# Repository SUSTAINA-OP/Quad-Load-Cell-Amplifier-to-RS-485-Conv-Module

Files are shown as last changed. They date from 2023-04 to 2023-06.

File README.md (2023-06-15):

<html lang="en">

<head>
	<meta charset="uft-8">
	<meta name="author" content="Masato Kubotera">
    <meta name="description" content="">
</head>

<body>
    <p><strong>This product is currently under development!</strong></p>
	<h1>Quad Load Cell Amplifier to RS-485 Conv. Module</h1>
        <p>
            This product can connect up to four load cells, and the change in resistance of the load cells can be amplified by an amplifier to 24 bit and sensed by a microcontroller at 80 Hz. This product uses a ready-made microcontroller board, simplifying PCB design and assembly of electronic components. For communication with the microcontroller, in addition to the USB connector on the microcontroller, RS-485 converted from UART  is available.<br>
            The RS-485 I/F connector has power input of up to 15 V. This allows servo motors with RS-485 I/F to be connected to the same bus as servo motors, etc.<br>
            The microcontroller that can be attached to this product is the <a href="https://www.seeedstudio.com/XIAO-c-1964.html?">XIAO series</a> manufactured by Seeed Studio. Select a microcontroller from the lineup according to the required performance.
            <br>
            <br>
            This product is developed as a foot load measurement module for SUSTAINA-OP<sup>TM</sup> and is used, for example, to estimate the position of the robot's center of mass.<br>
            In SUSTAINA-OP<sup>TM</sup>, four of the following load cells are connected to this module.
            <ul>
                <li><a href="https://www.alibaba.com/product-detail/SC700-Fishing-Scales-Small-Size-thin_60710601230.html">SC700-40kg (Sensor and Control Co., Ltd.)</a></li>
            </ul>
            The following microcontrollers are attached to this module.
            <ul>
                <li><a href="https://www.seeedstudio.com/Seeeduino-XIAO-Arduino-Microcontroller-SAMD21-Cortex-M0+-p-4426.html?">XIAO SAMD21 (Seeed Studio)</a></li>
            </ul>     
        </p>
	<h2>Features Rev. 1</h2>
        <p>
            <table>
                <tr>
                    <th>Top Surface of PCB</th>
                    <th>Bottom Surface of PCB</th>
                    <th>Assembled Electronic Components</th>
                </tr>
                <tr>
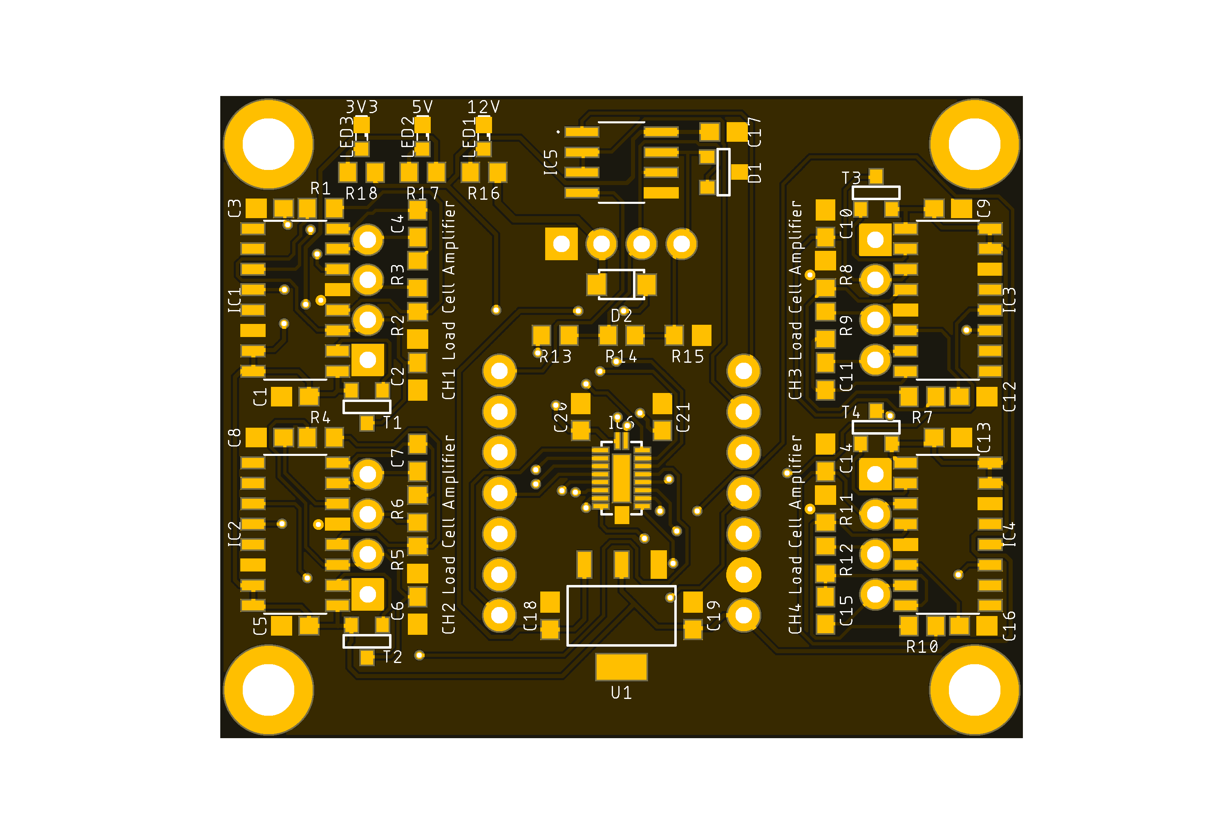
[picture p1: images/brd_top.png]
                    <td></td>
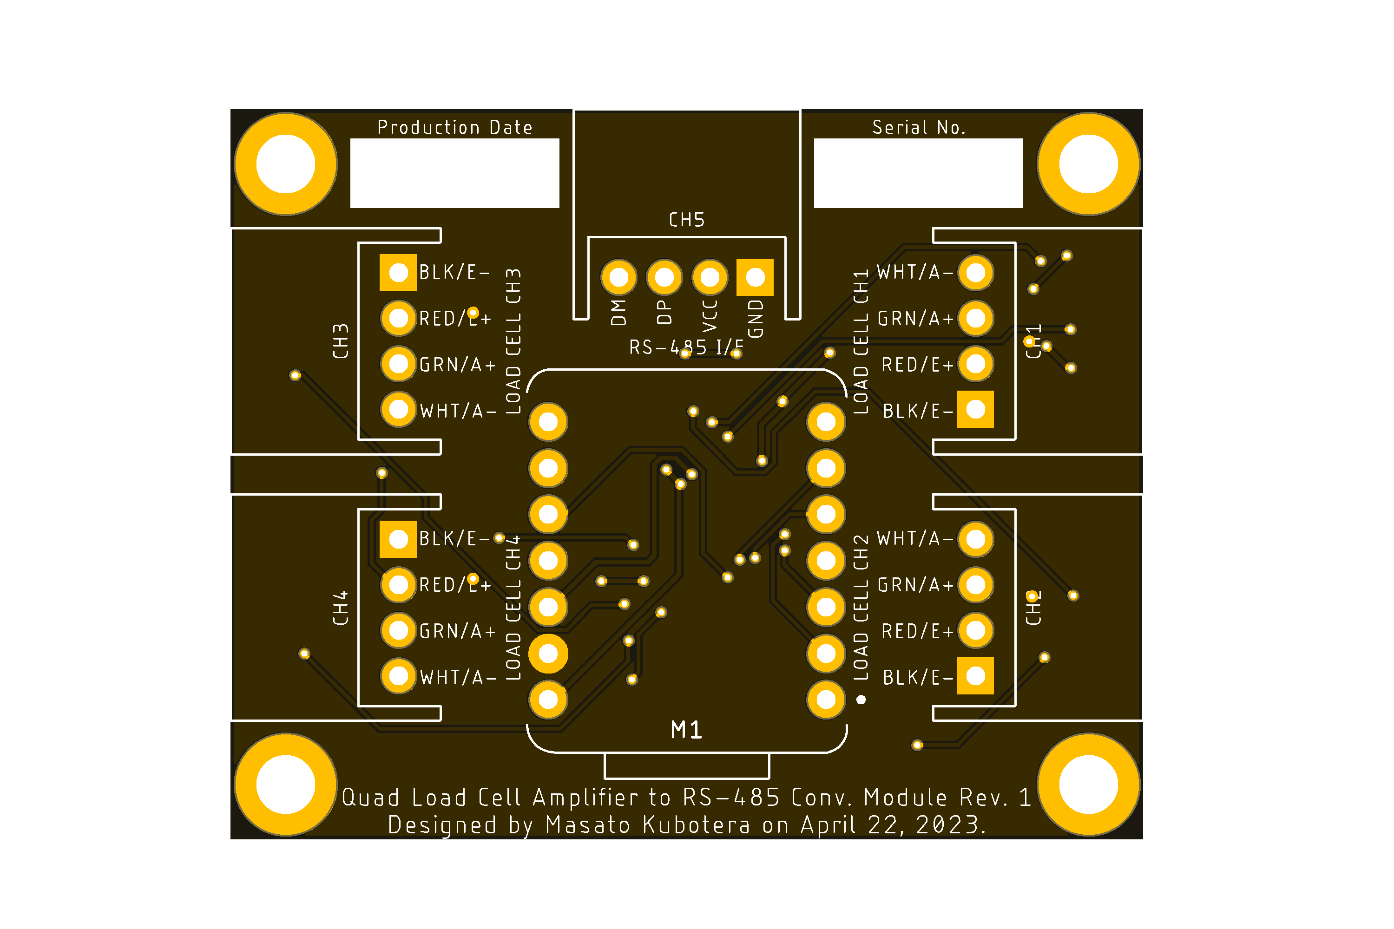
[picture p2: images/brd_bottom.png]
                    <td></td>
                    <td></td>
                </tr>
            </table>
        </p>
    <h3>PCB</h3>
        <p>
            <ul>
                <li>50 mm x 40 mm PCB layout</li>
                <li>4 x ø3.2 Mounting Holes</li>
                <li>
                    4 x Load Cell Ports
                    <ul>
                        <li>1" (2.54mm) pitch through-holes for XH connecter(JST)
                            <ul>
                                <li>BLK/E-: Excitation- (E-) or GND</li>
                                <li>RED/E+: Excitation+ (E+) or VCC</li>
                                <li>GRN/A+: Output+, Signal+, or Amplifier+</li>
                                <li>WHT/A-: Output-, Signal-, or Amplifier-</li>
                            </ul>
                        </li>
                    </ul>
                </li>
                <li>
                    1 x RS-485 I/F Port
                    <ul>
                        <li>1" (2.54mm) pitch through-holes for XH connecter(JST)
                            <ul>
                                <li>DM: RS-485 Data Signal Minus</li>
                                <li>DP: RS-485 Data Signal Plus</li>
                                <li>VCC: Power Input (Input voltage: 6.2~15V)</li>
                                <li>GND: Common Ground</li>
                            </ul>
                        </li>
                    </ul>
                </li>
            </ul>
        </p>
    <h3><a href="http://en.aviaic.com/detail/730856.html">AVIA HX711</a></h3>
        <p>
            <ul>
                <li>Two selectable differential input channels</li>
                <li>On-chip active low noise PGA with selectable gain of 32, 64 and 128</li>
                <li>On-chip power supply regulator for load-cell and ADC analog power supply</li>
                <li>On-chip oscillator requiring no external component with optional external crystal</li>
                <li>On-chip power-on-reset</li>
                <li>Simple digital control and serial interface: pin-driven controls, no programming needed</li>
                <li>Selectable 10SPS or 80SPS output data rate</li>
                <li>Simultaneous 50 and 60Hz supply rejection</li>
                <li>Current consumption including on-chip analog power supply regulator: normal operation < 1.5mA, power down < 1uA</li>
                <li>Operation supply voltage range: 2.6 ~ 5.5V</li>
                <li>Operation temperature range: -40 ~ +85C</li>
                <li>16 pin SOP-16 package</li>
            </ul>
        <p>
	<h2>Development Environments</h2>
    <p>
        This product is designed with the following software.
            <ul>
                <li><a href="https://www.autodesk.com/products/eagle/overview">Autodesk Eagle 9.6.2</a></li>
            </ul>
    </p>
    <h2>Repository Contents</h2>
        <p>
            <dl>
                <dt><a href="/images">\images</a></dt>
                <dd>PCB preview images and capture of design screen</dd>
                <dt><a href="/libraries">\libraries</a></dt>
                <dd>Libraries used in Autodesk Eagle design</dd>
                <dt><a href="/documents">\documents</a> </dt>
                <dd>Documentation for making and using this product</dd>
                <dt><a href="/pcb_order">\pcb_order</a> </dt>
                <dd>Gerber data and documentation for ordering PCB</dd>
                <dt><a href="/schematic.pdf">schematic.pdf</a></dt>
                <dd>Circuit diagram of this product</dd>
                <dt>*.brd</dt>
                <dd>Board wiring design file by Autodesk Eagle</dd>
                <dt>*.sch</dt>
                <dd>Circuit diagram design file by Autodesk Eagle</dd>
                <dt><a href="/.gitignore">.gitignore</a></dt>
                <dd>A file that tells Git not to track a particular file</dd>            <dt><a href="/LICENSE">LICENSE</a></dt>
                <dd>License to use this product</dd>
            </dl>
        </p>
    <h2>Documentation</h2>
        <p>
            The following documents are available for this product.
            <ul>
                <li><a href="/pcb_order/README.md">\pcb_order\README.md</a>: Information for ordering the PCB</li>
                <li><a href="/documents/BOM.md">\document\BOM.md</a>: List of electronic components assembled on the PCB</li>
            </ul>
        </p>
    <h2>References</h2>
        <p>
            This product was designed with reference to the following products.
            <ul>
                <li><a href="https://www.sparkfun.com/products/13879">SparkFun Load Cell Amplifier - HX711</a></li>
            </ul>
        </p>
    <h3>Acknowledgements</h3>
        <p>
            The development of this module is based on the following foot load measurement modules in the RoboCup Humanoid League.
            <ul>
                <li><a href="https://github.com/Rhoban/ForceFoot">Rhoban/ForceFoot</a>: Robotic foot design involving force sensors</li>
                <li><a href="https://github.com/bit-bots/bit_foot">bit-bots/bit_foot</a>: Foot pressure sensor for a humanoid robot</li>
            </ul>
            I would like to take this opportunity to thank you.
        </p>
    <h2>Contact</h2>
        <p>
            If you have any questions, please contact the designer of this product, Masato Kubodera, by <a href="mailto:masato.kubotera@sustaina-op.com">e-mail</a>.<br>
            E-mail: <a href="mailto:masato.kubotera@sustaina-op.com">masato.kubotera@sustaina-op.com</a>
        </p>
    <h2>License Information</h2>
        <p>
            This product is open source. Please review the <a href="/LICENSE">LICENSE</a> for license information.<br>
            <br>
            This product by Masato Kubotera is licensed under a <a href="http://creativecommons.org/licenses/by-nc-sa/4.0/">Creative Commons Attribution-NonCommercial-ShareAlike 4.0 International License</a>.
        </p>    
</body>
</html>

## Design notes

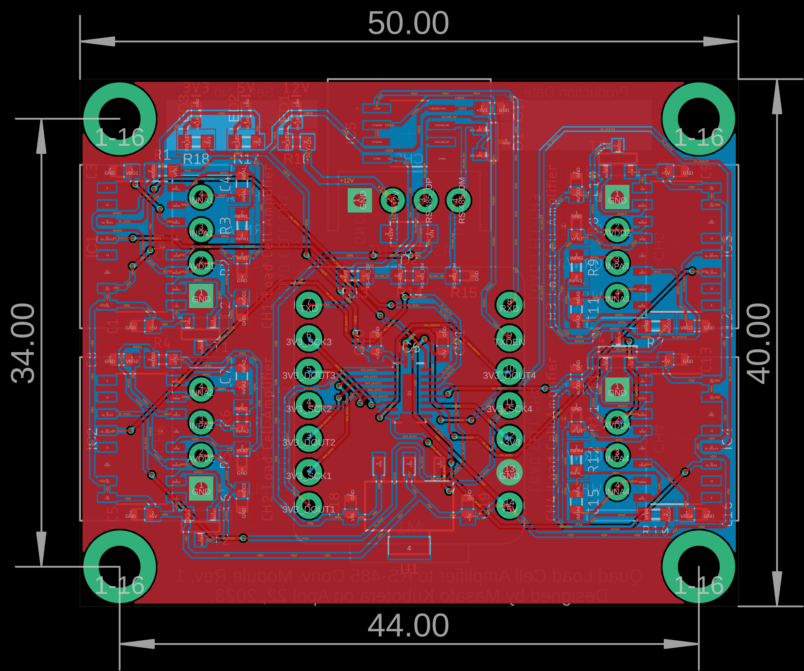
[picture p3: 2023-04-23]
images/brd.png

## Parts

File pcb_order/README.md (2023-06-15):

<html lang="en">

<head>
	<meta charset="uft-8">
	<meta name="author" content="Masato Kubotera">
    <meta name="description" content="">
</head>

<body>
	<h1>PCB Order</h1>
        <p>
            PCB/PCBA ordering were outsourced to <a href="https://jlcpcb.com/">JLCPCB</a>.<br>
            The following files were used to generate files for PCB/PCBA orders.
            <ul>
                <li>Eagle Design File:
                    <a href="https://github.com/JLCPCB/jlcpcb-eagle/blob/master/design%20rules/jlcpcb-2layers.dru">jlcpcb-2layers.dru</a>
                </li>
                <li>Eagle CAM File:
                    <a href="https://github.com/JLCPCB/jlcpcb-eagle/blob/master/cam/jlcpcb_2_layer_v9.cam">jlcpcb_2_layer_v9.cam</a>
                </li>
                <li>BOM/CPL Exporter ULPs:
                    <a href="https://github.com/JLCPCB/jlcpcb-eagle/blob/master/ulps/jlcpcb_smta_exporter.ulp">jlcpcb_smta_exporter.ulp</a>
                </li>
            </ul>
            These are distributed in <a href="https://github.com/JLCPCB/jlcpcb-eagle">github.com/JLCPCB/jlcpcb-eagle</a>.<br>
        </p>
    <h2>PCB Order Specifications</h2>
        <p>           
            <table>
                <tr>
                    <th>PCB Top Image</th>
                    <th>PCB Bottom Image</th>
                </tr>
                <tr>
                    <td></td>
                    <td></td>
                </tr>
            </table>
            The following  files used to order the PCB and their specifications. 
            <ul>
                <li>Gerber data: <a href="Gerber_date.zip">Gerber_date.zip</a></li>
            </ul>
            <details close>
                <summary>Click for more specifications</summary>
                <ul>                
                    <li>Base Material: FR-4</li>
                    <li>Layers: 2</li>
                    <li>Dimension: 50 mm * 40 mm</li>
                    <li>Product Type: Industrial/Consumer electronics</li>
                    <li>Different Design: 1</li>
                    <li>Delivery Format: Single PCB</li>
                    <li>PCB Thickness: 1.6</li>
                    <li>Impedance Control: no</li>
                    <li>PCB Color: 	Black</li>
                    <li>Silkscreen: White</li>
                    <li>Surface Finish: HASL(with lead)</li>
                    <li>Outer Copper Weight: 1 oz</li>
                    <li>Via Covering: Tented</li>
                    <li>Board Outline Tolerance: ±0.2mm(Regular)</li>
                    <li>Confirm Production file: No</li>                
                    <li>Remove Order Number: Yes</li>
                    <li>Deburring/Edge rounding: No</li>
                    <li>Flying Probe Test: Fully Test</li>
                    <li>Gold Fingers: No</li>
                    <li>Castellated Holes: No</li>
                    <li>4-Wire Kelvin Test: No</li>
                    <li>Paper between PCBs: No</li>
                    <li>Appearance Quality: IPC Class 2 Standard</li>
                    <li>Silkscreen Technology: Ink-jet/Screen Printing</li>
                    <li>Package Box: With JLCPCB logo</li>
                </ul>
            </details>
        </p>
    <h2>PCB Stencil Order Specifications</h2>
        <p>
                <details close>
                <summary>Click for more specifications</summary>
                <ul>                
                    <li>Framework: No</li>                
                    <li>Step Stencil: No</li>                
                    <li>Dimension: 50 mm * 40 mm</li>                
                    <li>Stencil Side: Top</li>                
                    <li>Electropolishing: Sanding</li>                
                    <li>Fiducials: No Fiducial</li>                
                    <li>Confirm Production file: No</li>
                </ul>
            </details>
        </p>
    </body>
</html>

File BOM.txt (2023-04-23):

Qty Value                  Device                 Package         Parts                                               Description                
3                          LEDSML0603             SML0603         LED1, LED2, LED3                                    LED                        
7   0.1u                   C-USC0603              C0603           C4, C7, C11, C15, C17, C20, C21                     CAPACITOR, American symbol 
2   10u                    C-USC0603              C0603           C18, C19                                            CAPACITOR, American symbol 
1   120                    R-US_R0603             R0603           R14                                                 RESISTOR, American symbol  
7   1k                     R-US_R0603             R0603           R3, R6, R9, R12, R16, R17, R18                      RESISTOR, American symbol  
12  1u                     C-USC0603              C0603           C1, C2, C3, C5, C6, C8, C9, C10, C12, C13, C14, C16 CAPACITOR, American symbol 
4   20k                    R-US_R0603             R0603           R1, R4, R7, R10                                     RESISTOR, American symbol  
2   680                    R-US_R0603             R0603           R13, R15                                            RESISTOR, American symbol  
4   8.2k                   R-US_R0603             R0603           R2, R5, R8, R11                                     RESISTOR, American symbol  
1   ADM3078E               ADM3078E               ADM3078E        IC5                                                                            
1   CDSOT23-SM712          CDSOT23-SM712          SOT-23-3        D1                                                                             
1   FXMA108BQX             FXMA108BQX             QFN-20          IC6                                                                            
4   HX711                  HX711                  HX711           IC1, IC2, IC3, IC4                                                             
1   LD1117S50              LD1117S50              SOT-223         U1                                                                             
4   MMBT3906               PNPSOT23               SOT-23          T1, T2, T3, T4                                      PNP TRANSISTOR             
5   S4B-XH-A               S4B-XH-A               S4B-XH-A        CH1, CH2, CH3, CH4, CH5                                                        
1   SEEED_XIAO_RP2040_HOLE SEEED_XIAO_RP2040_HOLE SEEED_XIAO_HOLE M1                                                                             
1   SS34FA                 SS34FA                 SS34FA          D2

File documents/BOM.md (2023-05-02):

<html lang="en">

<head>
	<meta charset="uft-8">
	<meta name="author" content="Masato Kubotera">
    <meta name="description" content="">
</head>

<body>
	<h1>BOM</h1>
        <p>
        The following electronic components are used for assembly on the PCB.
        <table>
                <tr>
                    <th>Top Designator</th>
                    <th>MFR.Part #</th>
                    <th>Distributor / Part #</th>
                    <th>Manufacturer</th>
                    <th>Part Detail</th>
                </tr>
                <tr>
                    <td>C1, C2, C3, C5, C6, C8, C9, C10, C12, C13, C14, C16</td>
                    <td>GRM188C81E105KA12</td>
                    <td><a href="https://akizukidenshi.com/catalog/g/gP-16993/">Akizuki / P-16993</a></td>
                    <td>Murata Electronics</td>
                    <td>Multilayer Ceramic Capacitor SMD 1uF 25V ±10% X6S 0603</td>
                </tr>
                <tr>
                    <td>C4, C7, C11, C15, C17, C20, C21</td>
                    <td>GCM188L81H104K57</td>
                    <td><a href="https://akizukidenshi.com/catalog/g/gP-16143/">Akizuki / P-16143</a></td>
                    <td>Murata Electronics</td>
                    <td>Multilayer Ceramic Capacitor SMD 0.1uF 50V ±10% X8L 0603</td>
                </tr>
                <tr>
                    <td>C18, C19</td>
                    <td>GRM188R6YA106MA73</td>
                    <td><a href="https://akizukidenshi.com/catalog/g/gP-13161/">Akizuki / P-13161</a></td>
                    <td>Murata Electronics</td>
                    <td>Multilayer Ceramic Capacitor SMD 10uF 35V ±20% X5R 0603</td>
                </tr>
                <tr>
                    <td>CH1, CH2, CH3, CH4, CH5</td>
                    <td>S4B-XH-A(LF)(SN)</td>
                    <td><a href="https://akizukidenshi.com/catalog/g/gC-12842/">Akizuki / C-12842</a></td>
                    <td><a href="https://www.jst-mfg.com/product/pdf/eng/eXH.pdf">JST</a></td>
                    <td>XH Connector Header 2.5mm-pitch 4-position Side Entry</td>
                </tr>
                <tr>
                    <td>D1</td>
                    <td>CDSOT23-SM712</td>
                    <td><a href="https://www.mouser.jp/ProductDetail/652-CDSOT23-SM712">Mouser / 652-CDSOT23-SM712</a></td>
                    <td><a href="https://www.bourns.com/products/diodes/diode-arrays/product/CDSOT23-SM712">BOURNS</a></td>
                    <td>TVS Diodes Array SMD 7V 400W SOT-23</td>
                </tr>
                <tr>
                    <td>D2</td>
                    <td>SS34FA</td>
                    <td><a href="https://www.mouser.jp/ProductDetail/512-SS34FA">Mouser / 512-SS34FA</a></td>
                    <td><a href="https://www.onsemi.com/products/discrete-power-modules/schottky-diodes-schottky-rectifiers/ss34fa">onsemi</a></td>
                    <td>Schottky Barrier Rectifier SMD 3A 40V</td>
                </tr>
                <tr>
                    <td>IC1, IC2, IC3, IC4</td>
                    <td>HX711</td>
                    <td><a href="https://akizukidenshi.com/catalog/g/gI-12473/">Akizuki / I-12473</a></td>
                    <td><a href="http://en.aviaic.com/detail/730856.html">Avia Semico</a></td>
                    <td>Analog To Digital Converters 24-bit SOP-16</td>
                </tr>
                <tr>
                    <td>IC5</td>
                    <td>ADM3078EARZ</td>
                    <td><a href="https://www.mouser.jp/ProductDetail/584-ADM3078EARZ-R7">Mouser / 584-ADM3078EARZ-R7</a></td>
                    <td><a href="https://www.analog.com/en/products/adm3078e.html">Analog Devices</a></td>
                    <td>RS-485/RS-422 Transceiver 16Mbps SMD SOIC-8</td>
                </tr>
                <tr>
                    <td>IC6</td>
                    <td>FXMA108BQX</td>
                    <td><a href="https://www.mouser.jp/ProductDetail/512-FXMA108BQX">Mouser / 512-FXMA108BQX</a></td>
                    <td><a href="https://www.onsemi.com/products/timing-logic-memory/standard-logic/level-translators/fxma108">onsemi</a></td>
                    <td>Level Translators 8-bit QFN-20</td>
                </tr>
                <tr>
                    <td>LED1, LED2, LED3</td>
                    <td>150060VS86000</td>
                    <td><a href="https://www.mouser.jp/ProductDetail/710-150060VS86000">Mouser / 710-150060VS86000</a></td>
                    <td><a href="https://www.we-online.com/components/products/datasheet/150060VS86000.pdf">Wurth Elektronik</a></td>
                    <td>Standard LED SMD 2V 20mA GREEN 573nm 0603</td>
                </tr>
                <tr>
                    <td>M1</td>
                    <td>Seeed XIAO RP2040</td>
                    <td><a href="https://www.mouser.jp/ProductDetail/713-102010428">Mouser / 713-102010428</a></td>
                    <td><a href="https://www.seeedstudio.com/XIAO-RP2040-v1-0-p-5026.html">Seeed Studio</a></td>
                    <td>RP2040 Microcontroller Board</td>
                </tr>
                <tr>
                    <td>R1, R4, R7, R10</td>
                    <td>RC0603FR-1320KL</td>
                    <td><a href="https://www.mouser.jp/ProductDetail/603-RC0603FR-1320KL">Mouser / 603-RC0603FR-1320KL</a></td>
                    <td>YAGEO</td>
                    <td>Thick Film Resistor SMD 20kΩ 1/10W ±1% 0603</td>
                </tr>
                <tr>
                    <td>R2, R5, R8, R11</td>
                    <td>RC0603FR-138K2L</td>
                    <td><a href="https://www.mouser.jp/ProductDetail/603-RC0603FR-138K2L">Mouser / 603-RC0603FR-138K2L</a></td>
                    <td>YAGEO</td>
                    <td>Thick Film Resistor SMD 8.2kΩ 1/10W ±1% 0603</td>
                </tr>
                <tr>
                    <td>R3, R6, R9, R12, R16, R17, R18</td>
                    <td>RC0603FR-101KL</td>
                    <td><a href="https://www.mouser.jp/ProductDetail/603-RC0603FR-101KL">Mouser / 603-RC0603FR-101KL</a></td>
                    <td>YAGEO</td>
                    <td>Thick Film Resistor SMD 1kΩ 1/10W ±1% 0603</td>
                </tr>
                <tr>
                    <td>R13, R15</td>
                    <td>RC0603FR-10680RL</td>
                    <td><a href="https://www.mouser.jp/ProductDetail/603-RC0603FR-10680RL">Mouser / 603-RC0603FR-10680RL</a></td>
                    <td>YAGEO</td>
                    <td>Thick Film Resistor SMD 680Ω 1/10W ±1% 0603</td>
                </tr>
                <tr>
                    <td>R14</td>
                    <td>RC0603FR-10120RL</td>
                    <td><a href="https://www.mouser.jp/ProductDetail/603-RC0603FR-10120RL">Mouser / 603-RC0603FR-10120RL</a></td>
                    <td>YAGEO</td>
                    <td>Thick Film Resistor SMD 120Ω 1/10W ±1% 0603</td>
                </tr>
                <tr>
                    <td>T1, T2, T3, T4</td>
                    <td>MMBT3906</td>
                    <td><a href="https://akizukidenshi.com/catalog/g/gI-05967/">Akizuki / I-05967</a></td>
                    <td><a href="">onsemi</a></td>
                    <td>Bipolar Transistor PNP 40V 200mA SOT-23</td>
                </tr>
                <tr>
                    <td>U1</td>
                    <td>LD1117S50</td>
                    <td><a href="https://akizukidenshi.com/catalog/g/gI-15255/">Akizuki / I-15255</a></td>
                    <td><a href="https://www.st.com/en/power-management/ld1117.html">STMicroelectronics</a></td>
                    <td>LDO Voltage Regulator 5.0V 0.8A</td>
                </tr>
            </table>
        </p>
</body>
</html>

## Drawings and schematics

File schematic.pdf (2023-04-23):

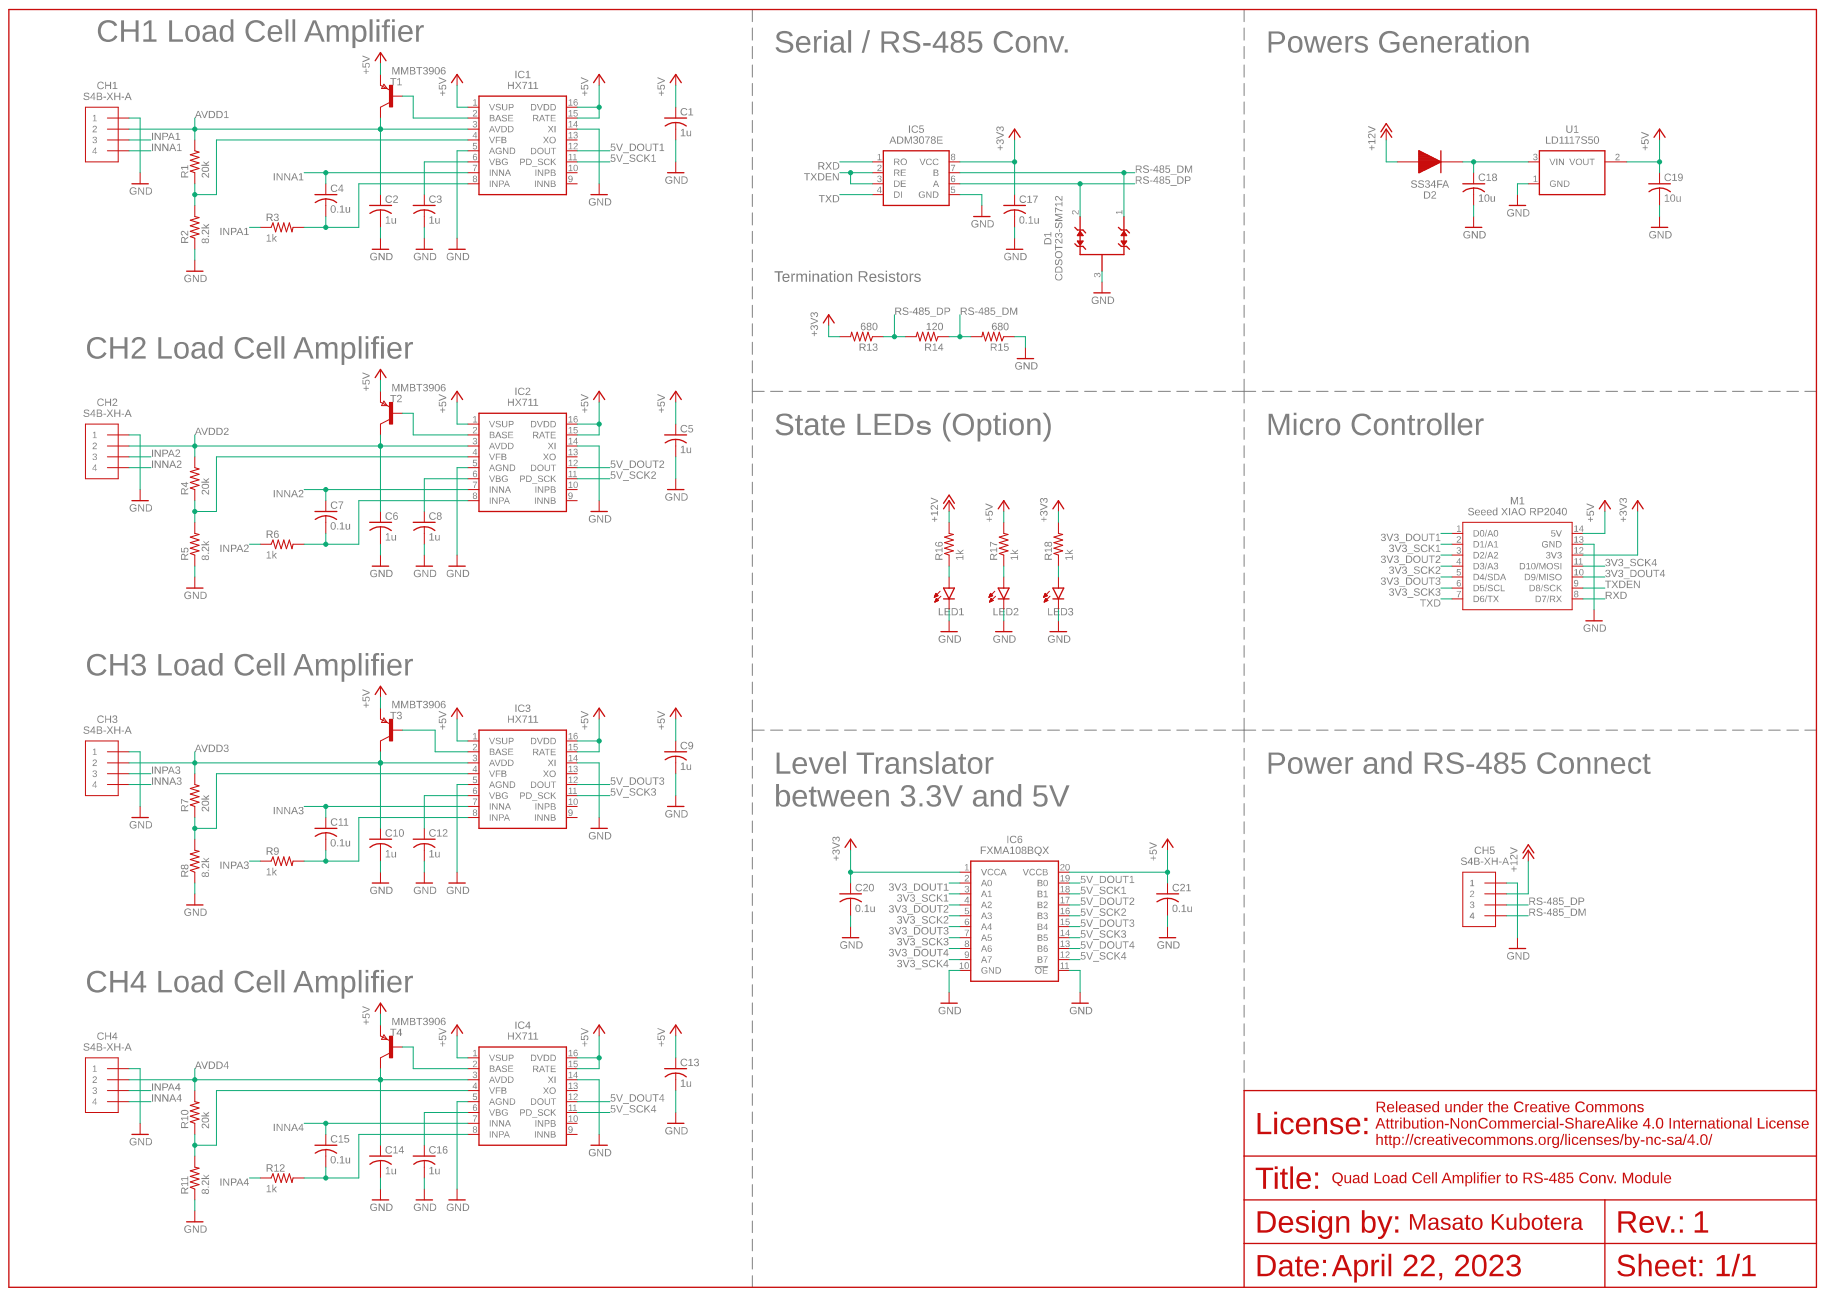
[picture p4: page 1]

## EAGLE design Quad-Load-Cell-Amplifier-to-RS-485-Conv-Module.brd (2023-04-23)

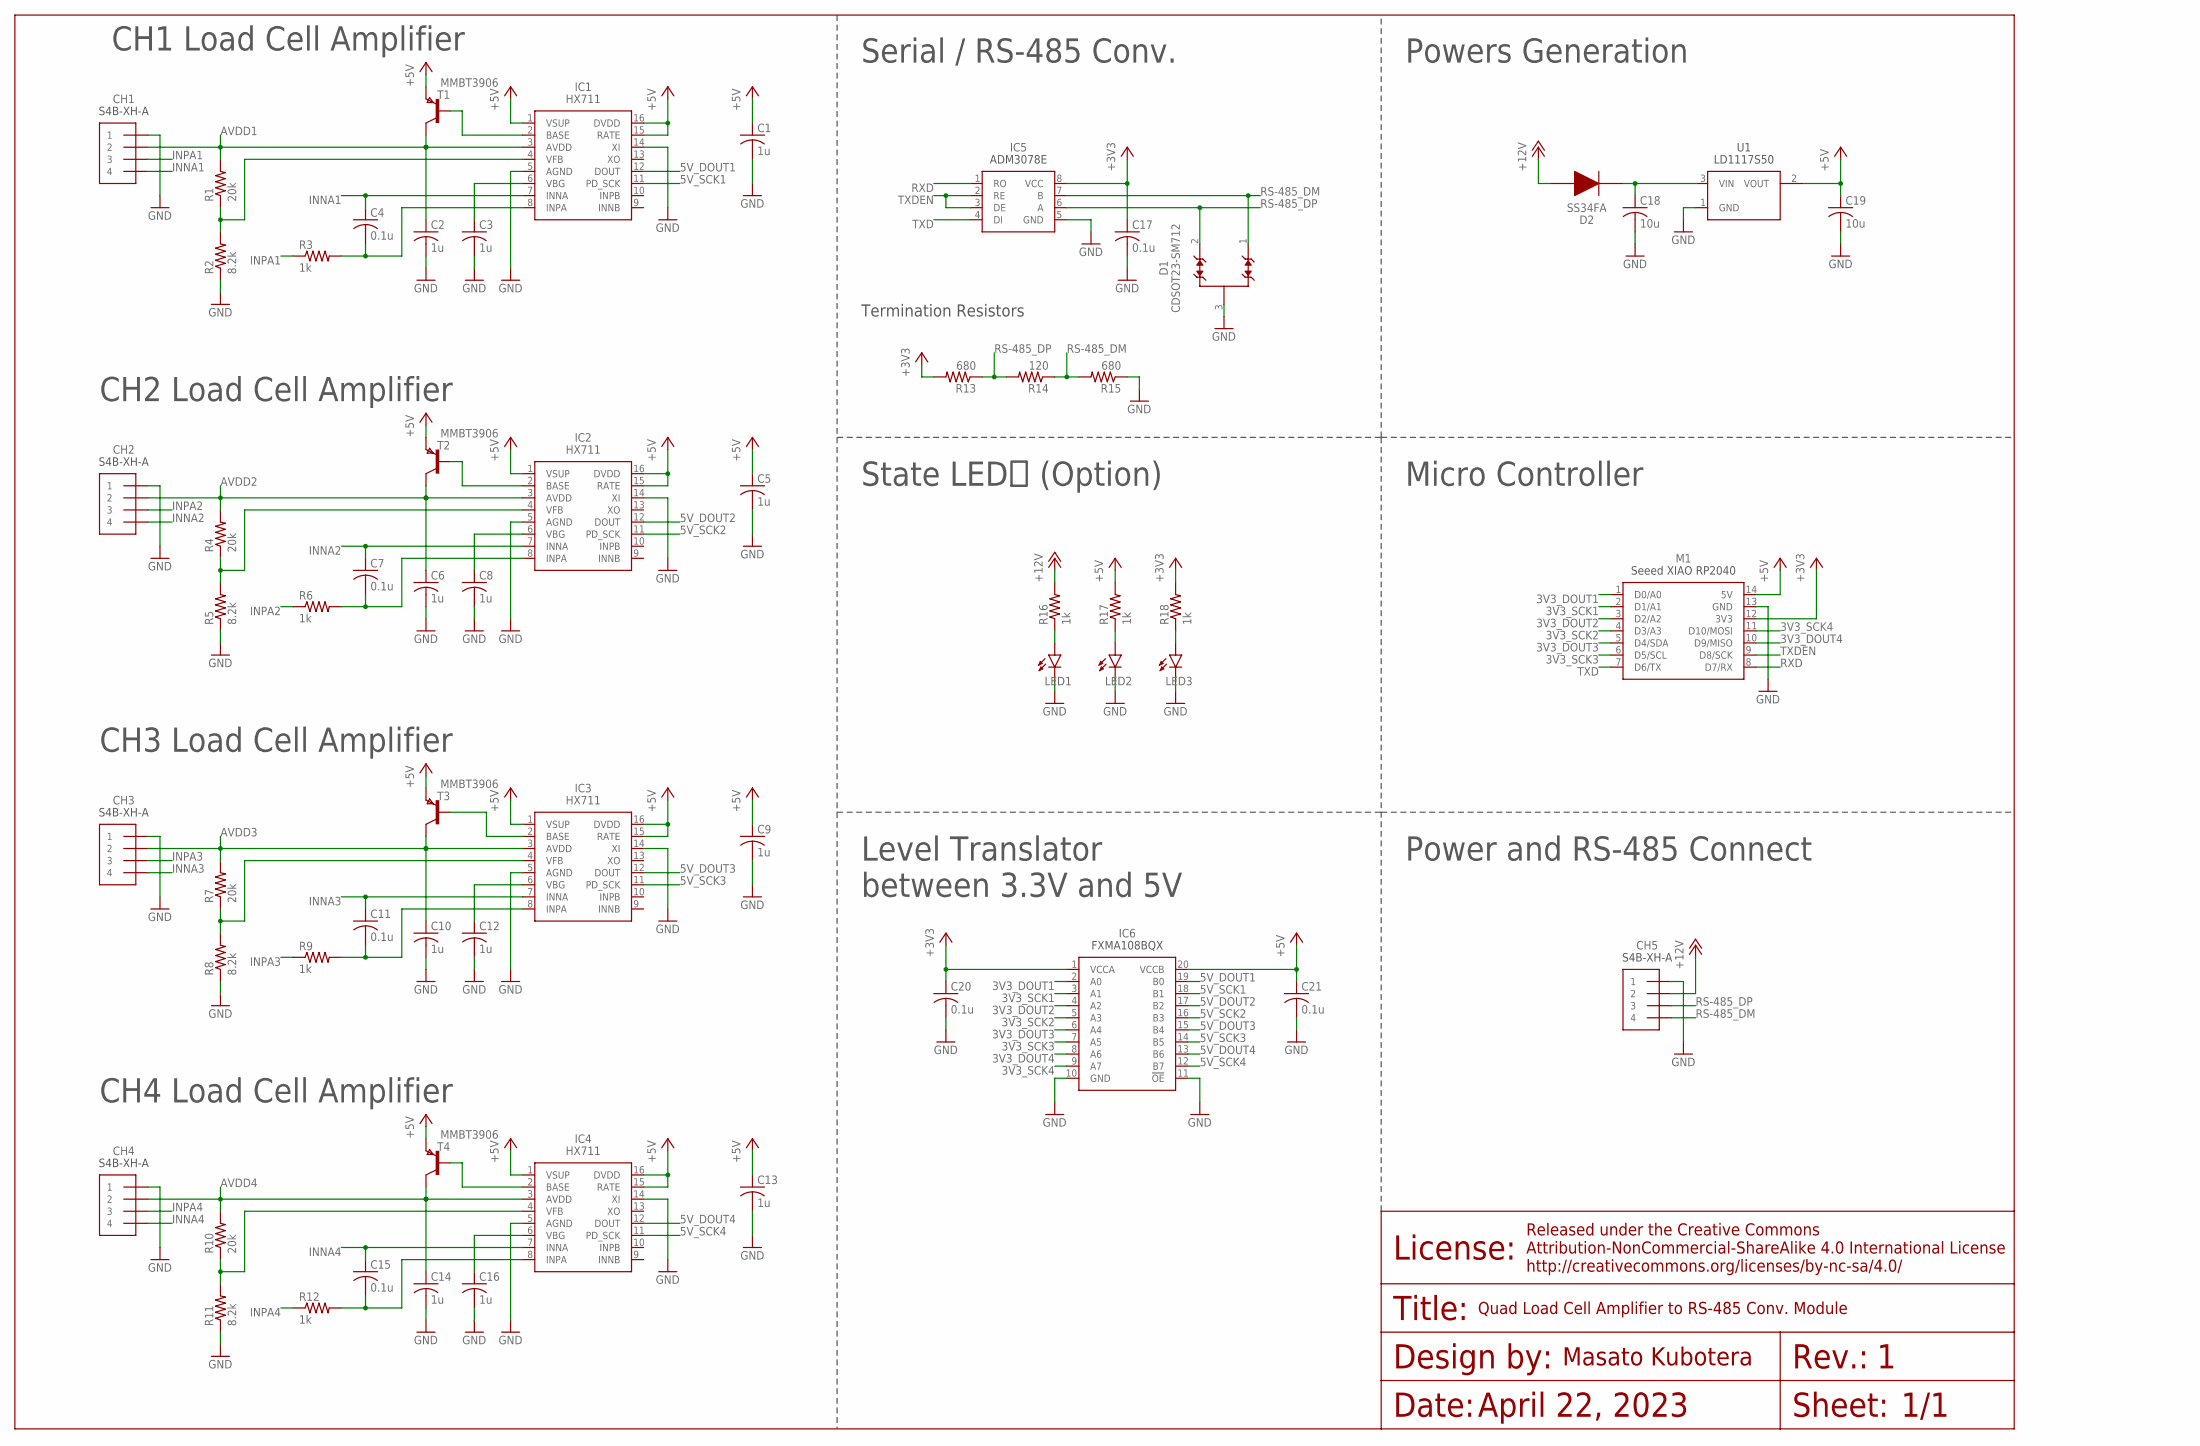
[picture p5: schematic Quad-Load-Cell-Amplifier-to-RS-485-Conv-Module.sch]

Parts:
C1, C2, C3, C5, C6, C8, C9, C10, C12, C13, C14, C16: 1u; C0603
C4, C7, C11, C15, C17, C20, C21: 0.1u; C0603
C18, C19: 10u; C0603
CH1, CH2, CH3, CH4, CH5: S4B-XH-A
D1: CDSOT23-SM712; SOT-23-3
D2: SS34FA
IC1, IC2, IC3, IC4: HX711
IC5: ADM3078E
IC6: FXMA108BQX; QFN-20
LED1, LED2, LED3: LEDSML0603; SML0603
M1: SEEED_XIAO_RP2040_HOLE; SEEED_XIAO_HOLE
R1, R4, R7, R10: 20k; R0603
R2, R5, R8, R11: 8.2k; R0603
R3, R6, R9, R12, R16, R17, R18: 1k; R0603
R13, R15: 680; R0603
R14: 120; R0603
T1, T2, T3, T4: MMBT3906; SOT-23
U1: LD1117S50; SOT-223

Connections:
3V3_DOUT1: IC6.2 (A0), M1.1 (D0/A0)
3V3_DOUT2: IC6.4 (A2), M1.3 (D2/A2)
3V3_DOUT3: IC6.6 (A4), M1.5 (D4/SDA)
3V3_DOUT4: IC6.8 (A6), M1.10 (D9/MISO)
3V3_LED: LED3.A, R18.1
3V3_SCK1: IC6.3 (A1), M1.2 (D1/A1)
3V3_SCK2: IC6.5 (A3), M1.4 (D3/A3)
3V3_SCK3: IC6.7 (A5), M1.6 (D5/SCL)
3V3_SCK4: IC6.9 (A7), M1.11 (D10/MOSI)
5V_DOUT1: IC1.12 (DOUT), IC6.19 (B0)
5V_DOUT2: IC2.12 (DOUT), IC6.17 (B2)
5V_DOUT3: IC3.12 (DOUT), IC6.15 (B4)
5V_DOUT4: IC4.12 (DOUT), IC6.13 (B6)
5V_LED: LED2.A, R17.1
5V_SCK1: IC1.11 (PD_SCK), IC6.18 (B1)
5V_SCK2: IC2.11 (PD_SCK), IC6.16 (B3)
5V_SCK3: IC3.11 (PD_SCK), IC6.14 (B5)
5V_SCK4: IC4.11 (PD_SCK), IC6.12 (B7)
12V_LED: LED1.A, R16.1
+3V3: C17.1, C20.1, IC5.8 (VCC), IC6.1 (VCCA), M1.12 (3V3), R13.2, R18.2
+5V: C1.1, C5.1, C9.1, C13.1, C19.1, C21.1, IC1.1 (VSUP), IC1.15 (RATE), IC1.16 (DVDD), IC2.1 (VSUP), IC2.15 (RATE), IC2.16 (DVDD), IC3.1 (VSUP), IC3.15 (RATE), IC3.16 (DVDD), IC4.1 (VSUP), IC4.15 (RATE), IC4.16 (DVDD), IC6.20 (VCCB), M1.14 (5V), R17.2, T1.2 (E), T2.2 (E), T3.2 (E), T4.2 (E), U1.2 (VOUT)
+12V: CH5.2, D2.2, R16.2
AVDD1: C2.1, CH1.2, IC1.3 (AVDD), R1.2, T1.1 (C)
AVDD2: C6.1, CH2.2, IC2.3 (AVDD), R4.2, T2.1 (C)
AVDD3: C10.1, CH3.2, IC3.3 (AVDD), R7.2, T3.1 (C)
AVDD4: C14.1, CH4.2, IC4.3 (AVDD), R10.2, T4.1 (C)
BASE1: IC1.2 (BASE), T1.3 (B)
BASE2: IC2.2 (BASE), T2.3 (B)
BASE3: IC3.2 (BASE), T3.3 (B)
BASE4: IC4.2 (BASE), T4.3 (B)
GND: C1.2, C2.2, C3.2, C5.2, C6.2, C8.2, C9.2, C10.2, C12.2, C13.2, C14.2, C16.2, C17.2, C18.2, C19.2, C20.2, C21.2, CH1.1, CH2.1, CH3.1, CH4.1, CH5.1, D1.3, IC1.5 (AGND), IC1.14 (XI), IC2.5 (AGND), IC2.14 (XI), IC3.5 (AGND), IC3.14 (XI), IC4.5 (AGND), IC4.14 (XI), IC5.5 (GND), IC6.10 (GND), IC6.11 (!OE), LED1.C, LED2.C, LED3.C, M1.13 (GND), R2.1, R5.1, R8.1, R11.1, R15.1, U1.1 (GND)
INNA1: C4.1, CH1.4, IC1.7 (INNA)
INNA2: C7.1, CH2.4, IC2.7 (INNA)
INNA3: C11.1, CH3.4, IC3.7 (INNA)
INNA4: C15.1, CH4.4, IC4.7 (INNA)
INPA1: CH1.3, R3.1
INPA1_: C4.2, IC1.8 (INPA), R3.2
INPA2: CH2.3, R6.1
INPA2_: C7.2, IC2.8 (INPA), R6.2
INPA3: CH3.3, R9.1
INPA3_: C11.2, IC3.8 (INPA), R9.2
INPA4: CH4.3, R12.1
INPA_: C15.2, IC4.8 (INPA), R12.2
RS-485_DM: CH5.4, D1.1, IC5.7 (B), R14.1, R15.2
RS-485_DP: CH5.3, D1.2, IC5.6 (A), R13.1, R14.2
RXD: IC5.1 (RO), M1.8 (D7/RX)
TXD: IC5.4 (DI), M1.7 (D6/TX)
TXDEN: IC5.2 (RE), IC5.3 (DE), M1.9 (D8/SCK)
VBG1: C3.1, IC1.6 (VBG)
VBG2: C8.1, IC2.6 (VBG)
VBG3: C12.1, IC3.6 (VBG)
VBG4: C16.1, IC4.6 (VBG)
VFB1: IC1.4 (VFB), R1.1, R2.2
VFB2: IC2.4 (VFB), R4.1, R5.2
VFB3: IC3.4 (VFB), R7.1, R8.2
VFB4: IC4.4 (VFB), R10.1, R11.2
VIN: C18.1, D2.1, U1.3 (VIN)

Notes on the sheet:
Serial / RS-485 Conv.
Powers Generation
Micro Controller
State LEDｓ (Option)
Power and RS-485 Connect
1/1
April 22, 2023
Quad Load Cell Amplifier to RS-485 Conv. Module
CH1 Load Cell Amplifier
Level Translator between 3.3V and 5V
Termination Resistors
CH2 Load Cell Amplifier
CH3 Load Cell Amplifier
CH4 Load Cell Amplifier

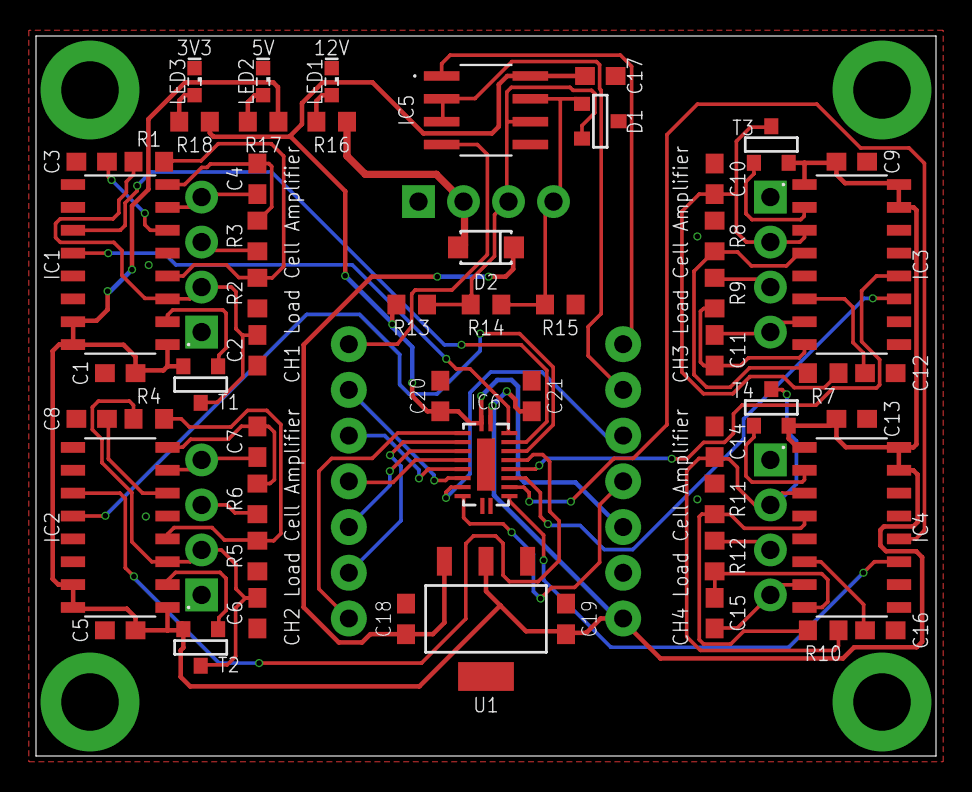
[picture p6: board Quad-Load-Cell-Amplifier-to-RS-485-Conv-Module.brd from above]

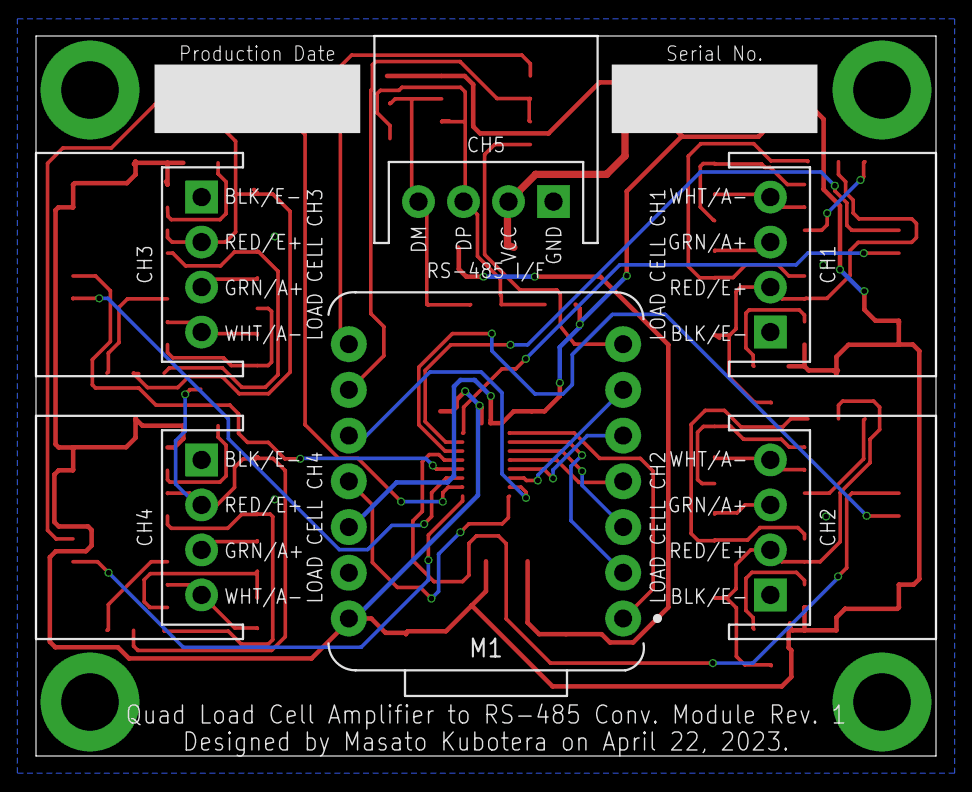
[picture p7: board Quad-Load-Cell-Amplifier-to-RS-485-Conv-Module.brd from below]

Board: 2 copper layers, 50.0 x 40.0 mm, 61 parts (6 on the bottom side), 57 nets.

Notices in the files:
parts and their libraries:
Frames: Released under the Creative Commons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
